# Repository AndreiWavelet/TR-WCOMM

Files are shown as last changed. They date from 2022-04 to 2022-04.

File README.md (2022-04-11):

# TR-WCOMM
This is an electronics and firmware project for a wireless file transmission device based on STM32L051 MCU and NRF24L01+ Transceiver. It's goal is to be small, low power, easy to use, easy to manufacture and to be able to send files over a outdoors distance of at least 100m. 

## What is looks like and how it works

The device is a small PCB with three LEDs in green, yellow and red, a push button, a SD Card socket and a U.FL antenna connector. There is space for mounting a battery connector ou  directly soldering battery leads to the PCB.

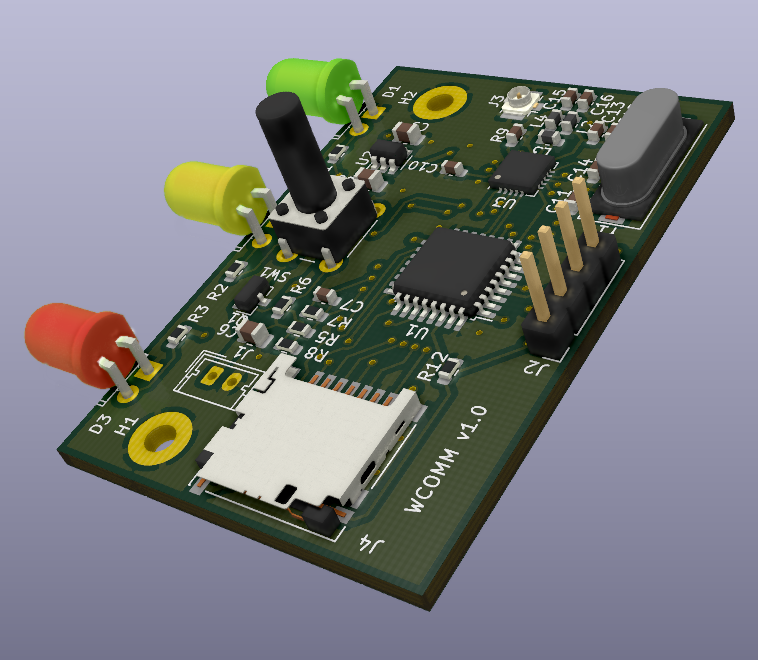
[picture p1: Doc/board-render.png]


Once there is power, the user must connect the antenna and the SD Card press once the push button. All three leds will flash thrice, indicating that the device is on. Then, the user can press the button briefly (<1s) to activate the file transmission. Another identical device can be used to receive the file. If the user presses the button for more than 3s, it will power off, flashing all leds 4 times.

By default, it will send the file "data.dat" at the root of the SD Card, but if user implements the file "wcomm.cfg" at the root of the SD Card, the name of the transmitted file, along with some other configuration, can be changed.

### wcomm.cfg file example

```
Example wcomm.cfg
file = myfile.bin
dest = 12345
addr = 23568
ch = 10
```

### wcomm.cfg attributes

|Attribute  |Meaning |
|:---:|:---:|
|file |Name of the file to be sent. |
|dest |Destination address, up to 5 characters. |
|addr |Device address for reception, up to 5 characters.  |
|ch |Channel to transmit and receive, 0-127. |

### LED Functions

Each led will flash in response to a successul operation, a warning or an error.

|LED Color  |Meaning |
|:---:|:---:|
|Green |A successful operation has been completed, or the device is in a safe working condition. |
|Yellow |There has been an error but the device has recovered, or the battery is weak. |
|Red |There has been an unrecoverable error (eg. SD Card failure) |

## Project Structure

The electronic schematics and board layout are located at the directory "Circuit" and the firmware code is located at the directory "Firmware". The electronic design was made with KiCad 5.1.12 and it's default libraries. The firmware design was made with STM32CubeIDE 1.9.0 and can be easily built with it. The firmware structure is further divided:

|Firmware Folder| Contents |
|:---:|:---:|
|Application |The main application code, with the vast majority of code writen by me. |
|Core |Device initialization code generated automatically by STM32CubeIDE  . |
|Drivers |Device drivers generated automatically by STM32CubeIDE. |
|FATFS |FatFs library diskio functions, mostly generated automatically by STM32CubeIDE. |
|Middlewares |Middleware code generated by STM32CubeIDE. |

## Principles of working

The device power is expected to be fed by a 3.7 V battery. This voltage is regulated to 3.3 V to power all the board. A transistor connected to both a MCU pin and the push button allows power to flow from the battery to the rest of the circuit. The device is built around a STM32L051 MCU. The SD Card and the NRF24L01+ share the same SPI bus.

The main firmware part is written in C++17 and uses a simple cooperative task architecture with methods Setup() and Loop(). Once the method Setup() of all tasks are called, the core proceeds to call every Loop() function forever. Usually, inside every Loop() function, a state-machine is built using switch statements.

The firmware is divided in two parts: drivers and applications. The drivers abstract the hardware in a modular way, exposing easy to use methods for each device. The applications make use of drivers to produce useful output.

### Drivers Description

|Driver | Description |
|:---:|:---:|
|Battery |Samples battery voltage and inform other tasks when it is too low. |
|Leds |Controls the LEDs operation. |
|NRF24L01p |Setups and controls NRF24L01+ Transceiver IC. |
|Power |Provide useful functions for low-power sleep and shutdown. |
|SpiManager |Manages the shared SPI bus between SD Card and NRF24L01+. |
|Switches |Provides the push button functionality with debounce and callback. |

### Applications Description

|Application | Description |
|:---:|:---:|
|Control |Controls the main functionality of the device: file transmission and power. |
|Main |Simple task scheduler. |
|SDCard |Provides abstraction to SD Card access to files. |
|TaskInterface  |Provides a standard interface for tasks to inherit from. |
|Tasks |List of tasks. |
|TickTimer |Simple, easy to use, timer to measure milliseconds ticks. |

### Low Power Features

The device features a low power oriented design. The SD Card can be turned off by a transistor to save power, and the microcontroller will go to low power stop mode when in idle state, waking up every 3 seconds, listening for any data for 1 second, and then going low power again. The NRF24L01+ Transceiver was choosen for being design-proven, flexible and, most importantly, low power.

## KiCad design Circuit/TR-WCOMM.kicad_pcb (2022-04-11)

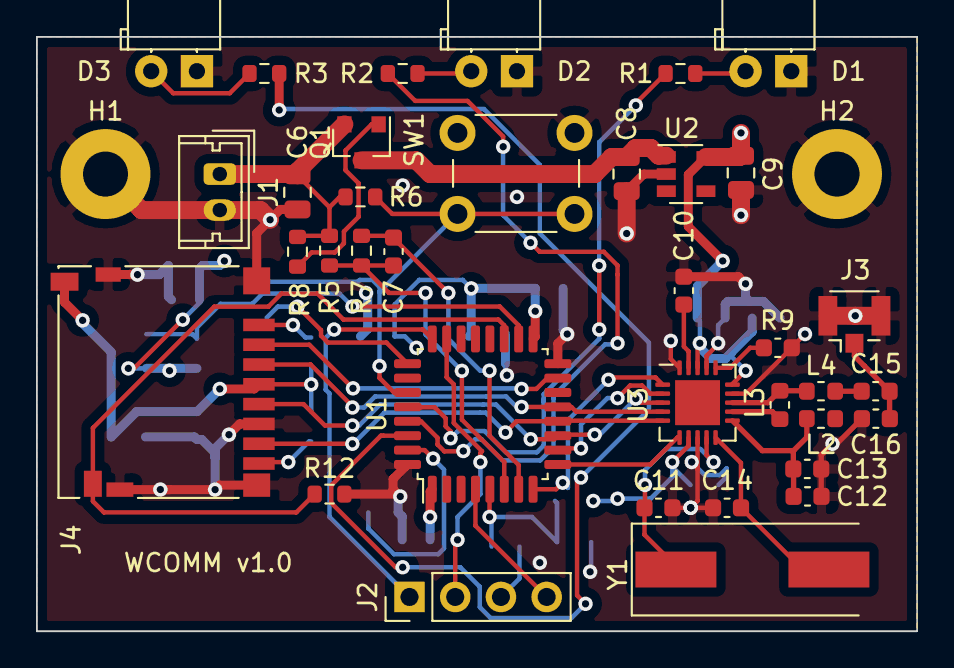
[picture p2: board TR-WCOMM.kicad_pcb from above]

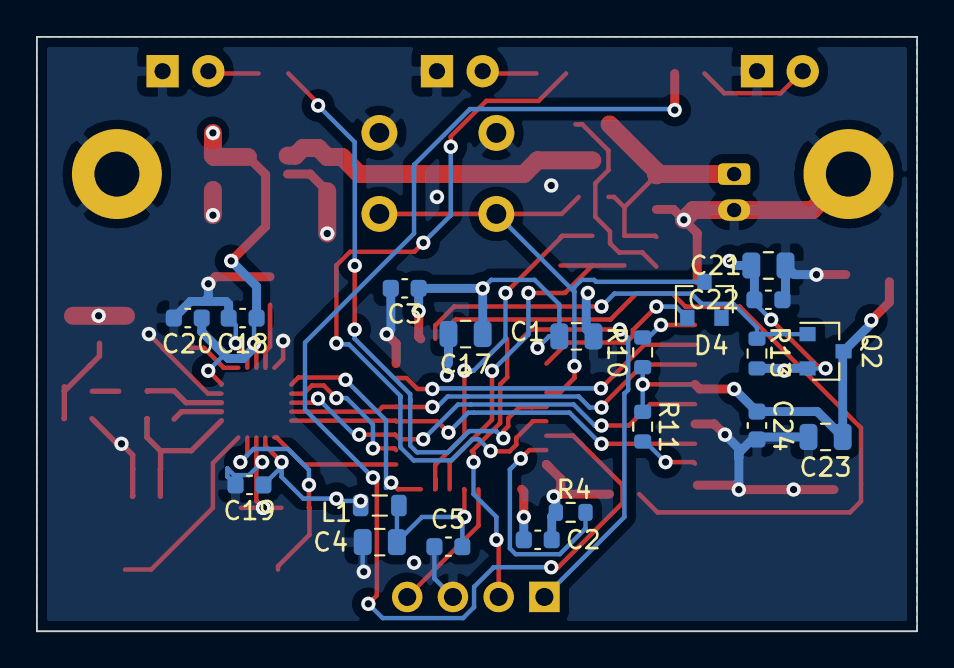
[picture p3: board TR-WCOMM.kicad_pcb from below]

Board: 4 copper layers, 48.9 x 33.0 mm, 58 parts (20 on the bottom side), 40 nets.

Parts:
C1, C4, C6, C8, C9, C17, C21, C23: 2u; C_0805_2012Metric
C2, C3, C5, C18, C19, C20, C22, C24: 100n; C_0603_1608Metric
C7: 1n; C_0603_1608Metric
C10: 33n; C_0603_1608Metric
C11, C14: 24p NPO; C_0603_1608Metric
C12: 2.2n; C_0603_1608Metric
C13: 4.7p NPO; C_0603_1608Metric
C15: 1.5p NPO; C_0603_1608Metric
C16: 1p NPO; C_0603_1608Metric
D1: LED G; LED_D5.0mm_Horizontal_O1.27mm_Z3.0mm
D2: LED Y; LED_D5.0mm_Horizontal_O1.27mm_Z3.0mm
D3: LED R; LED_D5.0mm_Horizontal_O1.27mm_Z3.0mm
D4: BAS19; SOT-23
H1, H2: MountingHole_Pad; MountingHole_2.5mm_Pad
J1: Conn_01x02; Molex_Micro-Latch_53253-0270_1x02_P2.00mm_Vertical
J2: Conn_01x04; PinHeader_1x04_P2.54mm_Vertical
J3: Conn_Coaxial; U.FL_Hirose_U.FL-R-SMT-1_Vertical
J4: Micro_SD_Card_Det; microSD_HC_Hirose_DM3D-SF
L1: 10u; L_0805_2012Metric
L2: 2.7n; L_0603_1608Metric
L3: 8.2n; L_0603_1608Metric
L4: 3.9n; L_0603_1608Metric
Q1, Q2: DMG2301L; SOT-23
R1, R2, R3: 100; R_0603_1608Metric
R4, R6, R10, R11, R12: 10k; R_0603_1608Metric
R5: 200k; R_0603_1608Metric
R7, R13: 100k; R_0603_1608Metric
R8: 570K; R_0603_1608Metric
R9: 22k; C_0603_1608Metric
SW1: SW_Push; SW_PUSH_6mm_H13mm
U1: STM32L041K6Tx; LQFP-32_7x7mm_P0.8mm
U2: TLV75533PDBV; SOT-23-5
U3: nRF24L01P; QFN-20-1EP_4x4mm_P0.5mm_EP2.5x2.5mm
Y1: 16M; Crystal_SMD_HC49-SD

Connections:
/3.3V: C1.1, C2.1, C3.1, C9.1, C17.1, C18.1, C19.1, C20.1, C21.1, C22.1, L1.1, Q2.2, R13.2, U1.1, U1.17, U2.5, U3.7, U3.15, U3.18
/GND: C1.2, C2.2, C3.2, C4.2, C5.2, C6.2, C8.2, C9.2, C10.2, C11.1, C12.2, C13.2, C14.2, C16.2, C17.2, C18.2, C19.2, C20.2, C21.2, C22.2, C23.2, C24.2, D1.1, D2.1, D3.1, H1.1, H2.1, J1.2, J2.3, J3.2, J4.6, J4.11, R4.2, R9.2, R12.2, SW1.1, U1.16, U1.32, U2.2, U3.8, U3.14, U3.17, U3.20
/MCU/BAT_FB: C7.1, R5.1, R7.1, U1.6
/MCU/LED_G: R1.1, U1.28
/MCU/LED_R: R3.1, U1.30
/MCU/LED_Y: R2.1, U1.29
/MCU/PWR_HOLD: D4.1, Q1.1, R8.1, U1.25
/MCU/SD_DET: J4.9, R12.1, U1.19
/MCU/SWCLK: J2.1, U1.24
/MCU/SWDIO: J2.2, U1.23
/MCU/VDDA: C4.1, C5.1, L1.2, U1.5
/MCU/~BAT_FB_EN: C7.2, R7.2, U1.7
/MCU/~PWR_BTN: D4.3, R6.2, SW1.2, U1.27
/MCU/~RST: J2.4, U1.4
/Power/VBAT+: C6.1, J1.1, Q1.2, R5.2, R6.1, R8.2
/SDCard/CS: J4.2, U1.15
/SDCard/DI: J4.3, U1.13, U3.4
/SDCard/DO: J4.7, U1.12, U3.5
/SDCard/SD_3.3V: C23.1, C24.1, J4.4, J4.10, Q2.3, R10.1, R11.1
/SDCard/~EN: Q2.1, R13.1, U1.18
/WirelessComm/CE: U1.8, U3.1
/WirelessComm/IRQ: U1.9, U3.6
/WirelessComm/SCK: J4.5, U1.11, U3.3
/WirelessComm/~CS: U1.10, U3.2
unnamed: C8.1, Q1.3, U2.1, U2.3
unnamed: C10.1, U3.19
unnamed: C11.2, U3.9, Y1.1
unnamed: C12.1, C13.1, L2.2, U3.11
unnamed: C14.1, U3.10, Y1.2
unnamed: C15.1, C16.1, J3.1
unnamed: C15.2, L4.2
unnamed: D1.2, R1.2
unnamed: D2.2, R2.2
unnamed: D3.2, R3.2
unnamed: J4.1, R10.2
unnamed: J4.8, R11.2
unnamed: L2.1, L3.2, U3.12
unnamed: L3.1, L4.1, U3.13
unnamed: R4.1, U1.31
unnamed: R9.1, U3.16

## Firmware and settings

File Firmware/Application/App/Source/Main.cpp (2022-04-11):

#include <App/Main.h>

#include <main.h>

#include <App/Tasks.h>

using namespace App;

Main::Main() : m_prevTicks(0), m_baseTicks(0){
	return;
}

Main::~Main(){
	return;
}

Main* Main::GetInstance(){
	static Main mn;
	return &mn;
}

void Main::Run(){
	Setup();
	for(;;){
		Loop();
	}
}

void Main::Setup(){
	m_prevTicks = HAL_GetTick();

	App::TaskManager::Setup();
}

void Main::Loop(){
	//ST Library HAL_GetTick will overflow after 2^32-1 ticks.
	//Detect this event and increment 1 on m_baseTicks so that Millis() can return a 64 bit integer.
	uint32_t millis = HAL_GetTick();
	if(millis<m_prevTicks){
		m_baseTicks ++;
	}
	m_prevTicks = millis;

	App::TaskManager::Loop();
}

uint64_t Main::Millis() const{
	//There is a small chance that HAL_GetTick overflows between a Loop() call and a Millis() call. Take care of it.
	uint32_t millis = HAL_GetTick();
	uint32_t bticks = m_baseTicks;
	if(millis<m_prevTicks){
		bticks++;
	}
	return (((uint64_t)bticks)<<32) + millis;
}

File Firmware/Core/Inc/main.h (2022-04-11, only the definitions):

#define BAT_FB_Pin GPIO_PIN_0
#define BAT_FB_GPIO_Port GPIOA
#define BAT_FB_nEN_Pin GPIO_PIN_1
#define BAT_FB_nEN_GPIO_Port GPIOA
#define RADIO_EN_Pin GPIO_PIN_2
#define RADIO_EN_GPIO_Port GPIOA
#define RADIO_IRQ_Pin GPIO_PIN_3
#define RADIO_IRQ_GPIO_Port GPIOA
#define RADIO_IRQ_EXTI_IRQn EXTI2_3_IRQn
#define RADIO_nCS_Pin GPIO_PIN_4
#define RADIO_nCS_GPIO_Port GPIOA
#define SD_nCS_Pin GPIO_PIN_1
#define SD_nCS_GPIO_Port GPIOB
#define SD_nEN_Pin GPIO_PIN_8
#define SD_nEN_GPIO_Port GPIOA
#define SD_DET_Pin GPIO_PIN_9
#define SD_DET_GPIO_Port GPIOA
#define SWDIO_Pin GPIO_PIN_13
#define SWDIO_GPIO_Port GPIOA
#define SWCLK_Pin GPIO_PIN_14
#define SWCLK_GPIO_Port GPIOA
#define PWR_HOLD_Pin GPIO_PIN_15
#define PWR_HOLD_GPIO_Port GPIOA
#define PWR_nBTN_Pin GPIO_PIN_4
#define PWR_nBTN_GPIO_Port GPIOB
#define PWR_nBTN_EXTI_IRQn EXTI4_15_IRQn
#define LED_G_Pin GPIO_PIN_5
#define LED_G_GPIO_Port GPIOB
#define LED_Y_Pin GPIO_PIN_6
#define LED_Y_GPIO_Port GPIOB
#define LED_R_Pin GPIO_PIN_7
#define LED_R_GPIO_Port GPIOB

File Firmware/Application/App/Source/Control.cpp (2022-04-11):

#include <App/Control.h>

#include <App/Main.h>
#include <App/SDCard.h>
#include <App/Tasks.h>

#include <Drivers/Battery.h>
#include <Drivers/Leds.h>
#include <Drivers/NRF24L01p.h>
#include <Drivers/Power.h>
#include <Drivers/SpiManager.h>
#include <Drivers/Switches.h>

#include <algorithm>
#include <cctype>
#include <string.h>

using namespace App;

static constexpr uint32_t POWER_ON_BLINKS = 3;
static constexpr uint32_t POWER_OFF_BLINKS = 5;
static constexpr uint32_t NRF_ERROR_BLINKS = 7;
static constexpr uint32_t CANT_OPEN_FILE_BLINKS = 3;
static constexpr uint32_t SDCARD_MISSING_BLINKS = 2;
static constexpr uint32_t NO_FILE_RECEPTOR_BLINKS = 1;

static constexpr uint32_t DEFAULT_BLINK_ON_TIME = 50; //[ms]
static constexpr uint32_t DEFAULT_BLINK_OFF_TIME = 350; //[ms]

static constexpr uint32_t SEND_REQUEST_TIME = 1000; //[ms]
static constexpr uint32_t POWER_OFF_TIME = 3000; //[ms]

static constexpr uint32_t SLEEP_TIME = 3000; //[ms]
static constexpr uint32_t RADIO_RX_TIME = 1000; //[ms]
static constexpr uint32_t FILE_TIMEOUT = 10000; //[ms]
static constexpr uint32_t FILE_ACCEPT_TIMEOUT = 300; //[ms]

static constexpr char WCOMM_CFG_FILE[] = "wcomm.cfg";
static constexpr char DEFAULT_FILE_TO_SEND[] = "data.dat";

static constexpr char MAX_FILE_LINE_LENGTH = 64;

typedef enum {
	csPOWER_ON, csWAIT_PERIPHERALS, csPARSE_CONFIG, csWAIT_TO_SLEEP, csSLEEP, csWAIT_SLEEP,
	csSTART_RADIO_RX, csWAIT_FILE_REQ_RX,
	csSEND_FILE_ACCEPT, csWAIT_SEND_FILE_ACCEPT, csRECEIVE_FILE,
	csSEND_FILE_TRANSFER_REQ, csWAIT_FILE_TRANSFER_REQ,
	csWAIT_FILE_ACCEPT,
	csSEND_FILE_PART, csWAIT_SEND_FILE_PART,
	csPOWER_OFF, csWAIT_POWER_OFF,
} State;

typedef enum {
	ptSEND_FILE, ptFILE_DATA, ptCANCEL, ptDONE, ptACCEPT_FILE
} PacketType;

Control::Control() : m_state(csPOWER_ON){
	strncpy(m_fileToSend,DEFAULT_FILE_TO_SEND,sizeof(m_fileToSend));
	return;
}

Control::~Control(){
	return;
}

bool Control::DoParseConfig(){
	//Basic parsing function.

	//Open config file.
	bool ok = m_fil.Open(WCOMM_CFG_FILE, false, true, true);
	if(!ok){
		return false;
	}

	//Scan all lines in file.
	while(m_fil.GetPosition()<m_fil.GetSize()){
		//Read next line.
		char dt[MAX_FILE_LINE_LENGTH];
		auto size = m_fil.ReadLine(dt, sizeof(dt));
		dt[size] = 0;

		//Setup parser.
		char* firstValue = nullptr;
		char* secondValue = nullptr;

        bool foundElem = false;
		char* firstAlnum = dt;
		char* lastAlnum = dt-1;

		//Find tokens.
		char* ch = dt;
		while(*ch!='\0'){
			//Find first and last alphanumeric character before '=' or '\0'.
			if(isalnum(*ch)){
				if(!foundElem){
					firstAlnum = ch;
					foundElem = true;
				}
				lastAlnum = ch;
			}

			if(!firstValue && *ch == '='){
				if(firstValue==nullptr){
					firstValue = firstAlnum;
					*(lastAlnum+1) = '\0';
					foundElem = false;
				}
				firstAlnum = ch;
				lastAlnum = ch-1;
			}
			ch++;
		}

		if(foundElem){
		    secondValue = firstAlnum;
			*(lastAlnum+1) = '\0';
		}

		if(firstValue && secondValue){
			ConvertToLowerCase(firstValue);
			ParseValuePair(firstValue, secondValue);
		}
	}

	m_fil.Close();

	return true;
}

void Control::ParseValuePair(const char* first, const char* second){
	//Parse value pairs.
	if(strncmp(first,"file",MAX_FILE_LINE_LENGTH)==0){
		strncpy(m_fileToSend,second,sizeof(m_fileToSend));
	}else if(strncmp(first,"txaddr",MAX_FILE_LINE_LENGTH)==0
			||strncmp(first,"dest",MAX_FILE_LINE_LENGTH)==0){
		Driver::NRF24L01p::Address addr;
		memset(addr.value,0,sizeof(addr.value));
		for(uint32_t t = 0;second[t]!='\0';addr.value[t] = second[t], t++);
		Tasks::NRF24L01p.SetTxAddress(addr);
	}else if(strncmp(first,"rxaddr",MAX_FILE_LINE_LENGTH)==0
			||strncmp(first,"addr",MAX_FILE_LINE_LENGTH)==0){
		Driver::NRF24L01p::Address addr;
		memset(addr.value,0,sizeof(addr.value));
		for(uint32_t t = 0;second[t]!='\0';addr.value[t] = second[t], t++);
		Tasks::NRF24L01p.SetRxAddress(addr);
	}else if(strncmp(first,"channel",MAX_FILE_LINE_LENGTH)==0
			||strncmp(first,"ch",MAX_FILE_LINE_LENGTH)==0){
		uint32_t ch = atoi(second);
		Tasks::NRF24L01p.SetChannel(ch);
	}
}

void Control::ConvertToLowerCase(char* dt){
	while(*(dt)!='\0'){
		*(dt) = tolower(*dt);
		dt++;
	}
}

bool Control::Sending() const {
	switch(m_state){
		case csSEND_FILE_TRANSFER_REQ:
		case csWAIT_FILE_TRANSFER_REQ:
		case csWAIT_FILE_ACCEPT:
		case csSEND_FILE_PART:
		case csWAIT_SEND_FILE_PART:
			return true;
		default:
			return false;
	}
}

void Control::OnReceiveRadioPacket(const void* data, uint32_t size){
	switch(m_state){
		case csWAIT_FILE_REQ_RX:
		{
			auto pkt = (const FileDescStruct*)data;
			if(size<sizeof(FileDescStruct) || pkt->pktType != ptSEND_FILE){
				return;
			}
			m_hasFileRxRequest = true;
			m_fileSize = size;
			strncpy(m_fileToWrite,pkt->filename,sizeof(m_fileToWrite));
			break;
		}
		case csRECEIVE_FILE:
		case csWAIT_SEND_FILE_ACCEPT:
		{
			if(size<1){
				return;
			}
			uint8_t type = *((const uint8_t*)data);
			switch(type){
				case ptFILE_DATA:
				{
					auto pkt = (const FileDataStruct*)data;
					const uint32_t PACKET_OVERHEAD = (sizeof(pkt) - sizeof(pkt->data));
					if(size<=PACKET_OVERHEAD){
						return;
					}
					auto dtWriteSize = size - PACKET_OVERHEAD;
					auto newpos = m_fil.Seek(pkt->ptr);
					if(newpos!=pkt->ptr){
						return;
					}

					auto written = m_fil.Write(pkt->data, dtWriteSize);
					if(written==dtWriteSize){
						m_writeSuccess = true;
					}
					break;
				}
				case ptCANCEL:
				{
					m_fileCancelRequest = true;
					break;
				}
				case ptDONE:
				{
					m_fileCompleteRequest = true;
					break;
				}
				case ptSEND_FILE:
				{
					m_fileCancelRequest = true;
					break;
				}
			}
			break;
		}
		case csWAIT_FILE_ACCEPT:
		{
			if(size<1){
				return;
			}
			uint8_t type = *((const uint8_t*)data);
			if(type==ptACCEPT_FILE){
				m_fileAcceptRequest = true;
			}
			break;
		}
	}
}

void Control::Setup(){
	Tasks::Switches.SetCallback(Driver::Switches::POWER, [this](bool state){
		if(state){
			return;
		}
		auto time = Tasks::Switches.TimeSincePressed(Driver::Switches::POWER);
		if(time<SEND_REQUEST_TIME){
			if(Sending()){
				m_fileCancelRequest = true;
			}else{
				m_sendRequest = true;
			}

		}else if(time>POWER_OFF_TIME){
			m_poffRequest = true;
			m_fileCancelRequest = true;
		}
	});
	Tasks::Switches.Reset(Driver::Switches::POWER);
}
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

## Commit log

2022-04-11 Add Board Render
2022-04-11 Add circuit.
    [Extra.sch, MCU.sch, MCUPower.sch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]
2022-04-11 Add STM32 HAL Libraries.

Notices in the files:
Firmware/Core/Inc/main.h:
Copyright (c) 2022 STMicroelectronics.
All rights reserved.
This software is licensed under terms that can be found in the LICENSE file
